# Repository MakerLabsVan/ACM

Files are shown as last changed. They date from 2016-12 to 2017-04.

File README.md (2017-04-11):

# ACM
This system logs and controls access to any machines that are connected to it.
ACM is a central Flask application connected to an Arduino, known as the Front Desk Arduino.
Each machine connected to the system has a module consisting of an Arduino with an RFID chip 
and WiFi capabilities. Every member receives a FOB programmed with their access conditions 
read from a Google Sheet.  
  
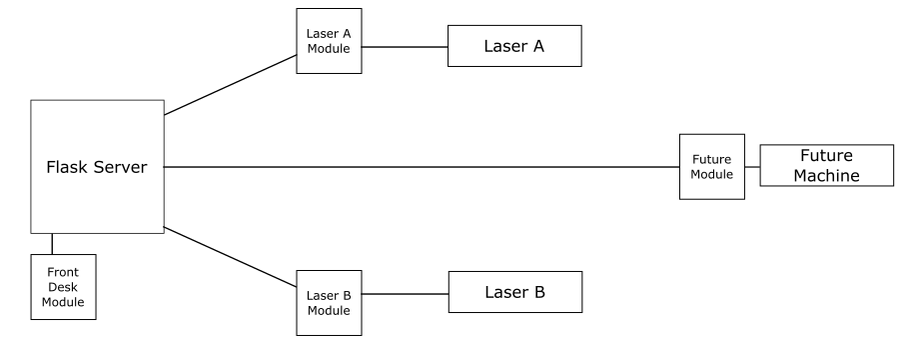
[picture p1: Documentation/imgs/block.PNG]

[block]: https://github.com/MakerLabsVan/ACM/blob/master/Documentation/imgs/block.PNG

# Database
A Google Spreadsheet is used by this app. There is a script (Tools->Script Editor) that runs 
every morning at 1am that goes through each member and determines if his/her membership cycle 
has completed. an email notification is then sent with the member's laser cutter time for that 
cycle. A daily summary is also included in this notification.

# Critical
All WiFi modules are configured to communicate to 192.168.0.200 on MakerLabs-Admin.  
The computer running the ACM app should have a static IP of 192.168.0.200 on MakerLabs-Admin.  
Documentation/wifitest/wifitest.ino should be used to reconfigure the WiFi modules.

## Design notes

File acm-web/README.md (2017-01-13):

# ACM Web Application  
This is a locally run application that serves as a web interface for ACM data and controlling the database. An RFID scanner
is attached through a serial connection to the application. This app can run on Windows, OS X and Linux.

# Requirements  
Flask (http://flask.pocoo.org)  
* SocketIO extension (https://flask-socketio.readthedocs.io/en/latest/)  

AngularJS  
* SocketIO (https://socket.io)  

Python 3 (https://www.python.org/downloads/) 
* PySerial (https://pythonhosted.org/pyserial/)  
* GSpread (https://gspread.readthedocs.io/en/latest/)  

# Installation  
1. Install Python 3 and Flask
2. Install PySerial, GSpread, and Flask-SocketIO modules
3. Follow OAuth2 procedure in GSpread documentation UNLESS still using original spreadsheet.  
   You will still need to install oauth2client `pip install --upgrade oauth2client` and PyOpenSSL `pip install PyOpenSSL`    
   Email Brian for authorization file. See OAuth2 procedure for details on how authorization is obtained.    
   In the database.py file, adjust the relative path to the JSON keyfile if needed.  
   `credentials = ServiceAccountCredentials.from_json_keyfile_name('../../acm-dashboard.json', scope)`
4. App is started by running `python3 server.py`

# Notes
* Photos are uploaded to amazon s3. Photo naming scheme is {id}.jpg

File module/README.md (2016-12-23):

# ACM Modules

This module is designed to authorize access to MakerLabs' laser cutter by an RFID tag. 
The system consists of an Arduino Uno, an RDM880 breakout board, and an ESP8266 breakout 
board. This module actively scans for RFID tags that follow the ISO14443A protocol. Details 
on ISO14443A, specifically MiFare, can be found in ACM/Documentation/ISO14443AB.pdf. This 
module also controls a relay which turns on support systems when a valid tag is detected.  

# Hardware Required
Arduino  
RDM880 (RFID reader)  
ESP8266 (WiFi module)      
LM1117 (3.3V linear regulator)   
IRL530 (n-channel MOSFET)     
LPD8806 LED strip

# Software Required
Arduino IDE  
  * SoftwareSerial library  
  * LPD8806 library
  
# Schematic  
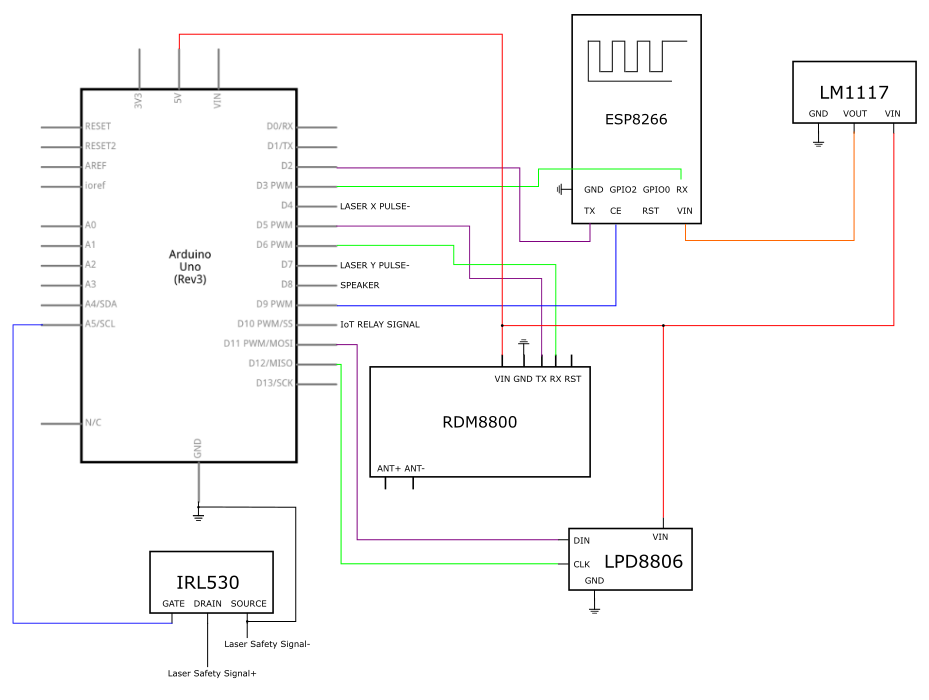
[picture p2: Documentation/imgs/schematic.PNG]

[schematic]: https://github.com/MakerLabsVan/ACM/blob/master/Documentation/imgs/schematic.PNG

# Other Parts and Notes  
__Level Shifter__  
[!alt text][levelshift]
[levelshift]: https://github.com/MakerLabsVan/ACM/blob/master/Documentation/imgs/levelshifter.PNG  
A level shifter is required. Here is an example using a voltage divider. Any value for R can be used as long as
the current going into the RX pin of the WiFi module does not exceed 12 mA.

__WiFi Serial Communication__  
The baud rate of the WiFi module varies with the supplier. Depending on the firmware version, 
the baud rate can be changed through the command set. Otherwise, firmware can be flashed to 
update the command set. The baud rate used here was 9600 for reliable performance with SoftwareSerial. YMMV.    
Tutorial: http://www.instructables.com/id/Intro-Esp-8266-firmware-update/

__Setting up the ESP8266__  
In Documentation/tests/wifi_test, there is a sketch that allows direct access to the ESP8266's serial console.
Upload it to the Arduino, open the serial monitor at 9600 baud and you will be able to use the AT command set as
shown in the command sheet under Documentation/datasheets.

# How It Works
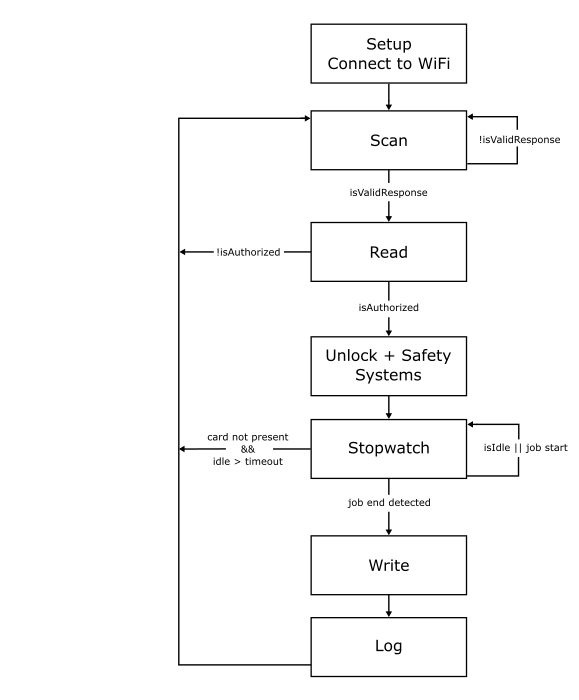
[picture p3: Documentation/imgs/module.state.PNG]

[modulestate]: https://github.com/MakerLabsVan/ACM/blob/master/Documentation/imgs/module.state.PNG  
In the stopwatch state, the module is monitoring the **LASER PLS-** signals of the X and Y motor controllers.
The state of the signals are polled approximately every second (defined as pollInterval) and stored in a circular 
buffer. If 5 (defined as sampleSize) valid signals in a row are detected, the module starts a stopwatch. 
When 5 invalid signals in a row are detected, the module ends the stopwatch and returns back to the main loop, 
where a log is sent to the Flask server.  

Note that there is a period of time where the log is happening between the job end and the start of the next 
loop when the laser cutter is **locked**. This period of time is approximately 3 - 4 seconds depending on 
the network.

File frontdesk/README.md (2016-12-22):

# ACM Front Desk Module

This module is part of the central Flask Server and communicates to it by a serial connection.
See the README in ACM/module for details on the hardware.  

# How It Works
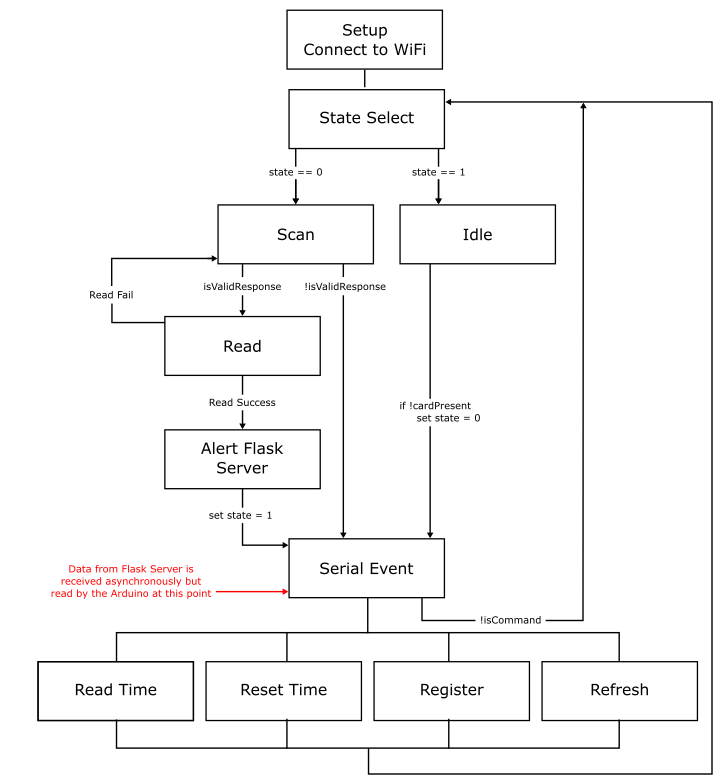
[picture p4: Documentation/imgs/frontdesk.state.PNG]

[frontdeskstate]: https://github.com/MakerLabsVan/ACM/blob/master/Documentation/imgs/frontdesk.state.PNG

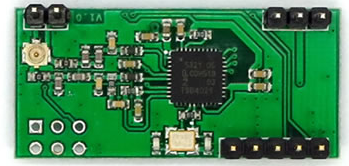
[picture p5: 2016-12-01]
Documentation/imgs/rdm8800.PNG

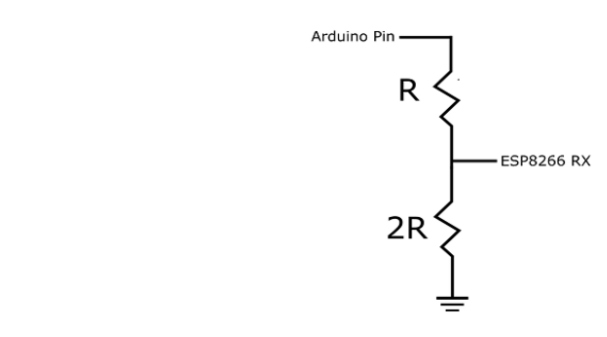
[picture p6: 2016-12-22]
Documentation/imgs/levelshifter.PNG

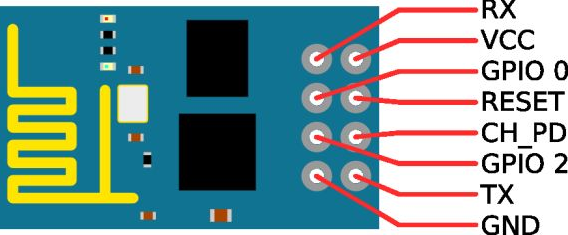
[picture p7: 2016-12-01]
Documentation/imgs/esp8266.PNG

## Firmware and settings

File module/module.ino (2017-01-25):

#include <SoftwareSerial.h>
#include <LPD8806.h>
#include "RFID.h"

#define MODULE

SoftwareSerial WIFI(WIFI_RX, WIFI_TX);
SoftwareSerial RFID(RFID_RX, RFID_TX);
LPD8806 LED = LPD8806(numLEDs, dataPin, clockPin);

int j = 0;

void setup() {
	// Set up pins
	pinMode(ledPin, OUTPUT);
	pinMode(driverX, INPUT);
	pinMode(driverY, INPUT);
	pinMode(speakerPin, OUTPUT);
  	pinMode(interlock, OUTPUT);
	pinMode(supportPin, OUTPUT);
  	pinMode(wifi_rst, OUTPUT);

	// Start with support systems off
	digitalWrite(supportPin, LOW);
	LED.begin();

	// Set up serial communication
	Serial.begin(monitorBaud);
	getStringFromMem(initialize);

	WIFI.begin(moduleBaud);
	connectWIFI();

	// Now listening to RFID serial port
	RFID.begin(moduleBaud);
	getStringFromMem(done);
}

void loop() {
	// some variables
	int8_t isStaff, isAuthorized, isValidResponse = 0;
	int16_t userID = 0;
	unsigned long existingTime, elapsedTime, totalTime = 0;
	unsigned char readData[bufferSize];
	// ----------------------------------------------------------------------
	// Turn LED off, lock laser cutter
	digitalWrite(ledPin, LOW);
	// ----------------------------------------------------------------------
	// Scan for RFID tags and see if support systems need to be off
	getStringFromMem(scan);
	while (!isValidResponse) {
		supportSystem(lastOn);
		sendCommand(CMD_GET_SNR, blockID, machineID, 0);
		delay(waitforSerialResponse);
		isValidResponse = getResponse(readData);
		rainbowCycle();	
	}
	// ----------------------------------------------------------------------
	// RFID tag detected, get user ID and authorization for this machine
	sendCommand(CMD_READ, blockID, userData, 0);
	delay(waitforReadResponse);
	isValidResponse = getResponse(readData);
	userID = (int16_t)getTime(readData, numUserBytes, userOffset);
	isStaff = (int8_t)readData[staffOffset] - ASCII_OFFSET;
	isAuthorized = (int8_t)readData[classOffset] - ASCII_OFFSET;
	// ----------------------------------------------------------------------
	// Read block that contains time data for this machine
	getStringFromMem(detected);
	sendCommand(CMD_READ, blockID, machineID, 0);
	delay(waitforReadResponse);
	isValidResponse = getResponse(readData);
	// -----------------------------------------------------------------------
	// Analyze response packet and data
	if (!isValidResponse) {
		red();		
		playDeath();
		digitalWrite(interlock, LOW);
		getStringFromMem(readUnsuccessful);
	}
	// These statements run if a valid RFID tag is detected
	else {
		// Translate the time data bytes to a value
		existingTime = getTime(readData, numTimeBytes, timeOffset);
		// Check if the user has taken the class and if the card has been initialized
		if ( !userID || !isAuthorized ) {
			red();
			playDeath();
			digitalWrite(interlock, LOW);
			getStringFromMem(notAuthorized);
		}
		// Check if the user has reached the 60 min quota, skip if staff member
		// else if ( (existingTime >= quota) && !isStaff ) {
		// 	red();
		// 	playDeath();
		// 	getStringFromMem(quotaMet);
		// }
		// User passed all checks and is able to use the machine
		// --------------------------------------------------------------------
		else {
			// Sound and text feedback
			green();						
			getStringFromMem(displayUsedTime);
			Serial.println(existingTime);
			getStringFromMem(user);
			Serial.print(userID);
			if (isStaff) {
				getStringFromMem(staff);
			}
			// getStringFromMem(authorized);

			// Ready to accumulate time
			// turn LED and support systems on
			// unlock laser cutter
			digitalWrite(ledPin, HIGH);
			digitalWrite(supportPin, HIGH);
      		digitalWrite(interlock, HIGH);
			elapsedTime = accumulator(readData, elapsedTime);
			totalTime = elapsedTime + existingTime;

			// Job done
			lastOn = millis();
			getStringFromMem(displayNewTime);
			Serial.println(totalTime);
		}
	}
	// -------------------------------------------------------------------------
	// Write time data to card
	if ( isRange(elapsedTime, freeTime, maxTime) ) {
		sendCommand(CMD_WRITE, blockID, machineID, totalTime);
		delay(waitforWriteResponse);
		isValidResponse = getResponse(readData);

		if (!isValidResponse) {
			getStringFromMem(errorRead);
		}
		else {
			getStringFromMem(cardUpdated);
			//delay(timeToRemoveCard);
		}
		// --------------------------------------------------------------------
  		// Push to ACM
		digitalWrite(ledPin, LOW);
		getStringFromMem(sendingLog);
		Serial.println(elapsedTime);
		WIFI.listen();
		updateACM(userID, elapsedTime, existingTime);
		// --------------------------------------------------------------------
		// Finished, prepare for next loop by switching to RFID serial port
		getStringFromMem(done);
		playCoinSound();					
	}
	else {
		Serial.println();
	}

	RFID.listen();
}
/*
	This function monitors the motor driver signals on the laser cutter.
	The signals are PWMs of a specific frequency. This function measures the
	period of any signal detected and accumulates time when valid signals
	are detected. A polling subroutine continuously checks if an RFID tag is 
	still present.
	
	Return: time accumulated
*/
unsigned long accumulator(unsigned char serialNumber[], unsigned long elapsedTime) {
	// some variables used in this scope
	unsigned long startTime, lastPollTime = 0;
	unsigned int periodX, periodY;
	int signals[] = { 0, 0, 0, 0, 0 };
  	int i, numValid, numInvalid, pollCounter = 0;

	if (debug) {
		Serial.print(F(" ")); Serial.print(startTime); Serial.print(F(" ")); Serial.println(elapsedTime);
	}
 
	while (1) {
		// Run approximately every second
		if (timeSince(lastPollTime) > pollInterval) {

			// Polling logic
			sendCommand(CMD_GET_SNR, blockID, machineID, 0);
			// if card is missing, increment a counter
			if (!getResponse(serialNumber)) {
				pollCounter += 1;
				// if the counter reaches a specified timeout, return
				if (pollCounter == pollTimeout) {
					//soundFeedback(isReject);
					getStringFromMem(cancel);
					elapsedTime = calcTime(startTime);

					// Any valid accumulated time will be returned
					if ( (startTime > 0) && isRange(elapsedTime, freeTime, maxTime) ) {
	          			return elapsedTime;
					}
					else {
						return 0;
					}
				}
			}
			else {
				digitalWrite(ledPin, HIGH);
				pollCounter = 0;
			}
			// End Polling Logic

			// Begin signal monitoring logic
			periodX = pulseIn(driverX, HIGH);
			periodY = pulseIn(driverY, HIGH);
	    	signals[i] = isRange(periodX + periodY, 0, maximumValue);

			// Only here temporarily for debugging
			// if (debug) {
			// 	Serial.print(F("PeriodX: ")); Serial.print(periodX); 
			// 	Serial.print(F(" PeriodY: ")); Serial.print(periodY);
			// 	Serial.print(F(" ")); Serial.print(signals[0]); Serial.print(signals[1]); Serial.print(signals[2]); Serial.print(signals[3]); Serial.print(signals[4]);
			// 	Serial.print(F(" ")); Serial.print(numValid); Serial.print(F(" ")); Serial.print(numInvalid);
			// 	Serial.print(F(" Start Time: ")); Serial.print(startTime);
			// 	if (startTime > 0) {
			// 		Serial.print(F(" Elapsed Time: ")); Serial.println(calcTime(startTime));
			// 	}
			// 	else {
			// 		Serial.println(F(" Elapsed Time: 0"));
			// 	}
			// }

			// if periodX and periodY IS a valid pair
			if (signals[i] == 1) {
				numValid += 1;
				numInvalid = 0;

				// a job is detected when we get enough valid signals in a row
				if (numValid == sampleSize) {
					// begin stopwatch
					if (startTime == 0) {
						startTime = millis();
					}
				}
			}

			// if periodX and periodY IS NOT a valid pair
			if (signals[i] == 0) {
				numValid = 0;
				numInvalid += 1;
				
				// check if enough negative signals have been detected
				if (numInvalid == sampleSize) {
					elapsedTime = calcTime(startTime);

					// if a job was detected, return
					if ( (startTime > 0) && isRange(elapsedTime, freeTime, maxTime) ) {
						return elapsedTime;
					}
					else {
						startTime = 0;
						elapsedTime = 0;
						numValid = 0;
						numInvalid = 0;
					}
				}
			}

			i < sampleSize - 1 ? i += 1 : i = 0;
	    	digitalWrite(interlock, HIGH);
			lastPollTime = millis();
		}
	}
}

void red() {
	LED.setPixelColor(0, LED.Color(68, 0, 5));
	LED.setPixelColor(1, LED.Color(127, 16, 25));
	LED.setPixelColor(2, LED.Color(127, 0, 0));
	LED.setPixelColor(3, LED.Color(84, 20, 15));
	LED.show();
}

void rainbowCycle() {
	j == 384 * 5 ? j = 0 : j++;
	for (int i = 0; i < LED.numPixels(); i++) {
		// tricky math! we use each pixel as a fraction of the full 384-color wheel
		// (thats the i / strip.numPixels() part)
		// Then add in j which makes the colors go around per pixel
		// the % 384 is to make the wheel cycle around
		LED.setPixelColor(i, Wheel( ((i * 384 / LED.numPixels()) + j) % 384) );
	}  
	LED.show();   // write all the pixels out
}

void green() {
	LED.setPixelColor(0, LED.Color(5, 0, 68));
	LED.setPixelColor(1, LED.Color(25, 16, 127));
	LED.setPixelColor(2, LED.Color(10, 0, 127));
	LED.setPixelColor(3, LED.Color(20, 14, 84));
	LED.show();
}

uint32_t Wheel(uint16_t WheelPos)
{
  byte r, g, b;
  switch(WheelPos / 128)
  {
    case 0:
      r = 127 - WheelPos % 128;   //Red down
      g = WheelPos % 128;      // Green up
      b = 0;                  //blue off
      break; 
    case 1:
      g = 127 - WheelPos % 128;  //green down
      b = WheelPos % 128;      //blue up
      r = 0;                  //red off
      break; 
    case 2:
      b = 127 - WheelPos % 128;  //blue down 
      r = WheelPos % 128;      //red up
      g = 0;                  //green off
      break; 
  }
  return(LED.Color(r,g,b));
}

void playCoinSound() {
	int coinNotes[] = { 988, 1319 };
	int coinNoteDurations[] = { 125, 400 };
	int numCoinNotes = numElements(coinNotes);

	for (int i = 0; i < numCoinNotes; i++) {
        tone(speakerPin, coinNotes[i]);
        delay(coinNoteDurations[i]);
        noTone(speakerPin);
    }
}

void playDeath() {
	int notes[] = { 247, 247, 247 };
	int numNotes = numElements(notes);

	for (int i = 0; i < numNotes; i++) {
		tone(speakerPin, notes[i]);
		delay(150);
		noTone(speakerPin);
		delay(150);
	}
}

void getStringFromMem(int index) {
	char stringBuffer[stringSize];
	strcpy_P(stringBuffer, (char*)pgm_read_word( &(message[index])) );
	Serial.print(stringBuffer);
}

void supportSystem(unsigned long lastOn) {
	// check if the support systems are on
	if (digitalRead(supportPin) == HIGH) {
		// check if it's been more than 5 mins
		// since the last card was scanned
		if (timeSince(lastOn) > supportTimeout) {
			digitalWrite(supportPin, LOW);
		}
		if (timeSince(lastOn) > interlockTimeout) {
			digitalWrite(interlock, LOW);
		}
	}
}

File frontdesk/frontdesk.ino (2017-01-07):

#include <SoftwareSerial.h>
#include <LPD8806.h>
#include "RFID.h"

#define FRONTDESK

SoftwareSerial RFID(RFID_RX, RFID_TX);
SoftwareSerial WIFI(WIFI_RX, WIFI_TX);

int j = 0;
LPD8806 LED = LPD8806(numLEDs, dataPin, clockPin);

int pollCounter, scannedID = 0;
unsigned char readData[bufferSize];

volatile bool isValidResponse = false;
volatile char characterRead[bufferSize];
volatile int state, id = 0;

void setup() {
	Serial.begin(moduleBaud);
	WIFI.begin(moduleBaud);
  	LED.begin();

	pinMode(ledPin, OUTPUT);
	pinMode(wifi_rst, OUTPUT);
	pinMode(speakerPin, OUTPUT);

	connectWIFI();
  	LED.show();
	RFID.begin(moduleBaud);
}

void loop() {
	// Scan
	if (state == 0) {
		sendCommand(CMD_GET_SNR, blockID, machineID);
		delay(waitforSerialResponse);
		isValidResponse = getResponse(readData);

		digitalWrite(ledPin, LOW);
		rainbowCycle();

		// If a tag is detected, read data and alert web app
		if (isValidResponse) {
			sendCommand(CMD_READ, blockID, userData);
			delay(waitforReadResponse);
			isValidResponse = getResponse(readData);

			// If data is successfully read, alert web app
			if (isValidResponse) {
				scannedID = (int)getTime(readData, numUserBytes, userOffset);

				// LEDs on
				green();
				digitalWrite(ledPin, HIGH);
				playCoinSound();
				WIFI.listen();
				
				// Constrain ID range for now... need to figure out why
				// large IDs are being sent randomly
				if ( isRange(scannedID, 0, 500) ) {
					scanTest(scannedID);
				}

				RFID.listen();
				state = 1;
			}
			else {
      			red();
				playDeath();
				state = 0;
			}
		}
	}
	// Other tag operations
	else if (state == 1) {
		sendCommand(CMD_GET_SNR, blockID, machineID);
		delay(waitforSerialResponse);
		isValidResponse = getResponse(readData);

		// If tag is removed, go back to scan state
		if (!isValidResponse) {
      		pollCounter++;
      		if (pollCounter == scan) {
        		state = 0;
        		pollCounter = 0;  
      		}
		}
	}
	// Go back to scan state otherwise
	else {
		state = 0;
	}
}

/* This functions runs after every time loop runs */
void serialEvent() {
	int i = 0;
	unsigned long existingTime = 0;

	while (Serial.available()) {
		// if no tag present, consume all data and send error
		if (state == 0) {
			while (Serial.available()) {
				Serial.read();
			}
			Serial.write(ERROR_CHAR);
			Serial.write(END_CHAR);
		}
		// otherwise, receive data and process
		else {
			characterRead[i] = Serial.read();
			i++;
		}
	}

	if (characterRead[0]) {
		// Read the time on card
		if (characterRead[0] == COMMAND_GET_TIME) {
			characterRead[0] = 0;

			sendCommand(CMD_READ, blockID, machineID);
			delay(waitforReadResponse);
			isValidResponse = getResponse(readData);
			existingTime = getTime(readData, numTimeBytes, timeOffset);

			// Send it to ACM
			while (existingTime) {
				Serial.write(existingTime);
				existingTime >>= eightBits;
			}
			
			Serial.write(END_CHAR);
		}

		// Reset the time on card
		else if (characterRead[0] == COMMAND_RESET_TIME) {
			characterRead[0] = 0;

			preparePayload(COMMAND_RESET_TIME, 0, 0, 0);
			sendCommand(CMD_WRITE, blockID, machineID);
			delay(waitforWriteResponse);

			Serial.write(done);
			Serial.write(END_CHAR);
		}

		else if (characterRead[0] == COMMAND_REGISTER) {
			characterRead[0] = 0;

			int numDigits = (int)(characterRead[1] - ASCII_OFFSET);		
			convertASCII(numDigits);

			preparePayload(COMMAND_REGISTER, id, numDigits, 0);
			sendCommand(CMD_WRITE, blockID, userData);
			delay(waitforWriteResponse);

			// Make sure time on card is zero when registered
			if (id) {
				preparePayload(COMMAND_RESET_TIME, 0, 0, 0);
				sendCommand(CMD_WRITE, blockID, machineID);
				while (id) {
					Serial.write(id);
					id >>= eightBits;
				}
			}

			Serial.write(END_CHAR);
			playUnderground();
		}

		// Update card permissions
		else if (characterRead[0] == COMMAND_REFRESH) {
			characterRead[0] = 0;
			
			int numDigits = (int)(characterRead[1] - ASCII_OFFSET);				
			convertASCII(numDigits);

			preparePayload(COMMAND_REGISTER, id, numDigits, 0);
			sendCommand(CMD_WRITE, blockID, userData);
			delay(waitforWriteResponse);

			while (id) {
				Serial.write(id);
				id >>= eightBits;
			}

			Serial.write(END_CHAR);
			playUnderground();
		}
	}
}

void convertASCII(int numDigits) {
	for (int i = 0; i < numDigits; i++) {
		id *= 10;
		id += (int)(characterRead[i+2] - ASCII_OFFSET);
	}
}

void getStringFromMem(int index) {
	char stringBuffer[stringSize];
	strcpy_P(stringBuffer, (char*)pgm_read_word( &(message[index]) ));
	Serial.print(stringBuffer);
}

void playCoinSound() {
	int coinNotes[] = { 988, 1319 };
	int coinNoteDurations[] = { 125, 400 };
	int numCoinNotes = numElements(coinNotes);

	for (int i = 0; i < numCoinNotes; i++) {
        tone(speakerPin, coinNotes[i]);
        delay(coinNoteDurations[i]);
        noTone(speakerPin);
    }
}

void playUnderground() {
	int notes[] = { 131, 262 };
	int numNotes = numElements(notes);

	for (int i = 0; i < numNotes; i++) {
		tone(speakerPin, notes[i]);
		delay(200);
		noTone(speakerPin);
	}
}

void playDeath() {
	int notes[] = { 247, 247, 247 };
	int numNotes = numElements(notes);

	for (int i = 0; i < numNotes; i++) {
		tone(speakerPin, notes[i]);
		delay(150);
		noTone(speakerPin);
		delay(150);
	}
}

void green() {
	LED.setPixelColor(0, LED.Color(5, 0, 68));
	LED.setPixelColor(1, LED.Color(25, 16, 127));
	LED.setPixelColor(2, LED.Color(10, 0, 127));
	LED.setPixelColor(3, LED.Color(20, 14, 84));
	LED.show();
}

void red() {
	LED.setPixelColor(0, LED.Color(68, 0, 5));
	LED.setPixelColor(1, LED.Color(127, 16, 25));
	LED.setPixelColor(2, LED.Color(127, 0, 0));
	LED.setPixelColor(3, LED.Color(84, 20, 15));
	LED.show();
}

void colorWipe(uint32_t c) {
	for (int i = 0; i < LED.numPixels(); i++) {
		LED.setPixelColor(i, c);
		LED.show();
	}
}

void rainbow() {
	j == 384 ? j = 0 : j++;

	for (int i = 0; i < LED.numPixels(); i++) {
		LED.setPixelColor(i, Wheel( (i + j) % 384));
	}
	LED.show();   // write all the pixels out
}

void rainbowCycle() {
	j >= 384 ? j = 0 : j += 7;

    for (int i = 0; i < LED.numPixels(); i++) {
		// tricky math! we use each pixel as a fraction of the full 384-color wheel
		// (thats the i / strip.numPixels() part)
		// Then add in j which makes the colors go around per pixel
		// the % 384 is to make the wheel cycle around
		LED.setPixelColor(i, Wheel( ((i * 384 / LED.numPixels()) + j) % 384) );
    }  

    LED.show();
}
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

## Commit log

2016-05-30 Added comments about circuit
2016-05-31 Added documentation and LED functionality
2016-06-02 Calibrated debounce delay
2016-06-06 fixed some errors, ready for testing
    [reader_test.ino]
2016-06-07 read/write combination does not work
    [writer_test.ino]
2016-06-07 testing, problem with serial timing
    [module.ino]
2016-06-14 Modified poll to not interfere with the return part of the accumulator function
    [module.ino]
2016-06-15 Communication between Arduino and Wi-Fi modulesuccessfully established
2016-06-16 400 Bad Request issue persists
    [wifi_test.ino]
2016-06-17 Version 2.05. Fixed time writing error.
    [module.ino]
2016-06-21 GET request successful. Need to find way to switch back to RFID functionality.
2016-06-21 successfully switched to RFID functionality by button press
2016-06-22 Added memory breakdown of card
    [CardProtocol.xlsx]
2016-06-22 Motor driver datasheet
2016-06-22 memory structure complete
    [CardProtocol.xlsx]
2016-06-22 Testing a PWM detector ISR
2016-06-24 enclosure design file
2016-06-24 tested on laser cutter
2016-06-24 created basic schematic of project
    [module.schematic.fzz]
2016-06-28 Test works without noise
    [pwm_detector_test.ino]
2016-06-30 filtering some data
2016-06-30 fixed bug in timestamping
    [pwm_detector_test.ino]
2016-07-04 Fixed bug in hardware serial declaration
    [pwm_detector_test.ino]
2016-07-04 Found that when cutter is off, noise can trigger a log to send
    [pwm_detector_test.ino]
2016-07-04 Adding pwm logs for debugging
2016-07-04 Added PWM data
2016-07-04 Added delay before time log to send at correct intervals
    [pwm_detector_test.ino]
2016-07-04 integrated new pwm signal detector
2016-07-04 RFID tag stuck on reader to continue logging
    [module.ino]
2016-07-04 Fixed typo in polling logic
    [module.ino]
2016-07-05 Fixed bug in ThingSpeak log
    [RFID.h, module.ino]
2016-07-05 Added one more valid pair for drivers
2016-07-05 Fixed bug in valid pair detection
    [module.ino]
2016-07-05 fixing bug in writing new time
    [module.ino]
2016-07-05 Found that module.ino does not process Arduino String data type correctly.
    [module.ino]
2016-07-05 Fixing String datatype error
    [RFID.h, module.ino]
2016-07-05 String concatenation not working in 2nd function call
    [RFID.h, module.ino]
2016-07-07 Fixed flaw where removing card would not update ThingSpeak
    [module.ino]
2016-07-07 Fixed bug where module would not activate WiFi serial port
    [module.ino]
2016-07-13 Reverted back to rising edge logic
    [module.ino]
2016-07-14 Design file for enclosure
2016-07-18 Clean up. Fixed overflow issue
    [module.ino]
2016-07-18 This version is for the Arduino with integrated WiFi
2016-07-19 Adding serial debugging for small laser
2016-07-19 Code was in wrong branch of repo
    [RFID.h]
2016-07-20 Monitoring small laser cutter
2016-07-21 Modified to monitor small laser
2016-07-23 new enclosure
2016-07-24 small laser enclosure
2016-07-25 Fixing bug related to RFID not initializing if on Uno WiFi
    [module.ino]
2016-07-25 Testing blinking LED at polling
2016-07-25 Fixed bug in function declaration
    [module.ino]
2016-07-26 Signal detection is not working
    [RFID.h, module.ino]
2016-07-26 Testing on small laser
2016-07-26 Fixed bug in string retrieving
    [RFID.h, module.ino]
2016-08-03 Added error check for time data
    [frontdesk.ino]
2016-08-04 Fixed bug in serial printing
    [module.ino]
2016-08-04 Fixed bug in front desk minutes calculation
    [frontdesk.ino, module.ino]
2016-08-08 Fixed bug in signal validation
    [RFID.h]
2016-08-08 Switching to timed polling instead of delaying
2016-08-08 Testing LED blink when card not detected during job
2016-08-08 Testing LED blink when card not detected during job 2
2016-08-08 Testing LED blink when card not detected during job 3
2016-08-15 Testing LED blink on poll
2016-08-15 LED blink causing issues with serial monitor
    [module.ino]
2016-08-15 Removed LED logic
2016-08-18 Fixed bug in staff member detection. Need to update all staff cards
    [RFID.h, module.ino]
2016-08-18 Fixed small laser wifi module
    [wifi_test.ino]
2016-08-22 Fixed bugs in front desk
    [frontdesk.ino, module.ino]
2016-08-23 Started on mini web app to control arduino through serial port
2016-08-24 One way communication with Arduino established
2016-08-24 Able to send command to turn on and off LED
2016-08-24 Successfully tested two way communication between PC and Arduino
2016-08-24 Testing get time and reset functions from web interface
    [frontdesk.ino]
2016-08-24 Created class that interfaces with arduino
2016-08-25 debugging issue with port synchronization
    [arduino.py]
2016-08-25 Determined cause of serial comm failure
    [arduino.py, constant.py, frontdesk.ino]
2016-08-25 Successfully controlled front desk acm through serial port. Returns correct time as well
    [arduino.py, constant.py, frontdesk.ino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]
2016-08-26 Modified all function names and replaced all references
    [arduino.py, constant.py, serialcommtest.ino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]
2016-08-30 Added error checking for cards that aren't scanned
    [arduino.py, constant.py, server.py]
2016-08-30 Removed error check and now adding wait
    [arduino.py, constant.py]
2016-08-30 testing an error check
    [arduino.py]
2016-09-03 Successfully send data from web app form to arduino and parsed correctly
    [frontdesk.ino]
2016-09-06 Fixing bug where only 1 card can be registered in one session
    [frontdesk.ino]
2016-09-06 Added auto reset to card after registration
    [frontdesk.ino]
2016-09-06 Changed name of button
2016-09-07 Testing automatic calculation of laser time cost
2016-09-07 Added auto calculation of drop in laser rate
2016-09-08 Fixed bug in choosing host
    [arduino.py]
2016-09-08 Added hole for keychain
2016-09-23 Fixed bug in time not writing to card. Modified delay
    [RFID.h]
2016-09-23 Fixing bug in writing to card
    [RFID.h, module.ino]
2016-09-23 Fixed data type of authorization
    [module.ino]
2016-09-26 Successfully tested insert of user
2016-09-27 Fixed and synced up user model
    [constant.py, database.py]
2016-09-27 Reverting to previous version due to bugs in writing
    [RFID.h, module.ino, module_rfid.ino]
2016-09-27 Reverting to previous version due to bug in writing
    [module.rfid.ino, module.wifi.ino]
2016-09-27 RFID was not finished sending data before Arduino stopped listening. Modified listen function. Fixed writing bug
    [RFID.h, module.rfid.ino]
2016-09-27 Fixed redeclaration of variables
    [frontdesk.ino]
2016-09-29 Fixing conflicts from merge
    [RFID.h, frontdesk.ino, module.rfid.ino]
2016-09-30 Testing Arduino WiFi with web app
2016-09-30 Accidentally pulled wrong branch. Reverting changes
    [server.py]
2016-09-30 Testing api call from arduino uno
2016-09-30 Arduino Uno Wifi only works with thingspeak... testing
2016-10-01 Changing main loop to only scan for cards. Serial interrupt will handle commands
2016-10-01 Fixed bug in one time scanning
    [frontdesk.ino]
2016-10-01 Added error check for id being zero
    [frontdesk.ino]
2016-10-01 Beginning laser cutter log api
2016-10-01 Successfully tested laser log api
2016-10-01 Successfully posted to laser log sheet. Need to integrate with modules
2016-10-03 Successfully tested laser cutter log api call
2016-10-04 done logging for laser cutter
2016-10-04 Fixed bug in datetime implementation
    [database.py, server.py]
2016-10-04 Modifying print formatting
2016-10-04 fixed a comment about converting byte stream to number
    [arduino.py]
2016-10-04 Added lifetime laser cutter time
2016-10-04 Reactivated arduino
2016-10-04 Fixed bug in logging time
    [database.py]
2016-10-04 Removed laser access option
2016-10-05 Removing lifetime log. Causing bugs
    [database.py]
2016-10-05 Fixed bug where arduino received ascii
    [RFID.h, module.ino]
2016-10-06 Reverting front-desk to prev version
    [frontdesk.ino]
2016-10-06 successfully tested socket, integrating into app
2016-10-07 Currently working, but need to integrate with angular
2016-10-07 implemented on arduino
2016-10-07 removing arduino section for testing
2016-10-12 Logging lifetime laser time and month's laser time
2016-10-12 Removed socket until needed
2016-10-12 Fixed bug with return values
    [database.py]
2016-10-13 Cut down on extra api calls
2016-10-14 Printing authorization time
2016-10-14 Fixed bug with timedelta function. Added total_seconds
    [database.py]
2016-10-18 Added missing time variable
    [module.ino]
2016-10-18 Fixed bug with header file
    [RFID.h]
2016-10-18 Changing support pin to an available digital pin
2016-10-19 Removed unnecessary row check code. Found bug was due to token refresh. Got rid of microseconds in time data as well.
    [database.py, server.py]
2016-10-19 Forgot to uncomment arduino code
2016-10-20 Added wifi module to frontdesk arduino. Successfully communicated with server
2016-10-20 Added scan log and testing new laser log
2016-10-20 Fixed logging of guest cards
    [database.py, server.py]
2016-10-20 only adding to db if arduino successfully registers
2016-10-20 Fixed return value bug
    [database.py]
2016-10-20 Fixed tab and spacing error
    [database.py]
2016-10-20 data now refers to correct element
    [database.py]
2016-10-21 Adding socket
2016-10-21 Socket tested and working
2016-10-21 Fixed reference to data
    [server.py]
2016-10-21 Fixed off by one error when logging
    [database.py]
2016-10-21 Added constant for laser times
2016-10-24 Adding quick fix for scan errors
    [frontdesk.ino]
2016-10-25 trying to do tab pane switch in angular
2016-10-26 Switched all ACM related modules to Admin network
2016-10-26 Tab pane switching logic is done through angular now
2016-10-27 adding quick fix for scan log
    [server.py]
2016-10-27 Centered registration button. Added more user info
2016-10-27 Fixed non display of laser time
2016-10-28 Button highlights
2016-10-28 Added button disable until a response is received. Prevents button spamming
    [server.py]
2016-10-28 testing auto switch to main tab on scan
2016-10-31 Reactivated arduino code
2016-11-03 Added led strip logic
2016-11-03 testing led strip
2016-11-03 Fixed drop in charge display
2016-11-03 Testing other LED functions
2016-11-03 Testing LED changes
2016-11-03 Added bad read sound
    [module.schematic.fzz]
2016-11-03 case plans
2016-11-04 Added hole for barrel jack
2016-11-04 Added hole for usb
2016-11-04 Fixed bug in call to web app
    [frontdesk.ino]
2016-11-05 Ready to cut
2016-11-06 Fixed styling of submit buttons
2016-11-06 Added error msg when command is sent with no card present
    [frontdesk.ino]
2016-11-06 raspi enclosure
2016-11-09 Cut down on sound effects
2016-11-09 Fixed app freeze when sending command without card present
    [frontdesk.ino]
2016-11-09 Fixing bug with staff offset
    [server.py]
2016-11-09 LED strip added
2016-11-09 Testing auto reset time every month
    [server.py]
2016-11-10 Shorten registration/refresh sound lenght
    [frontdesk.ino]
2016-11-16 Updated drop in charge on scan
2016-11-16 fixing drop in charge
2016-11-20 Added another socket event for refresh status
2016-11-23 Testing method that replaces an existing users id with a new one
    [database.py, server.py]
2016-11-24 Testing user id replacement
    [server.py]
2016-11-30 Checking laser log
2016-12-01 pin details
2016-12-02 Hiding laserB
2016-12-06 Added schematic, cleaned up files
2016-12-06 added colour to schematic
2016-12-06 Fixed pin assignment. Added LED strip.
2016-12-06 Added speaker pin
2016-12-08 Arduino does not support C++ optional param feature. It supports overloading.
2016-12-08 Fixed reset time return value
    [frontdesk.ino]
2016-12-15 Clean up and reactivated arduino
2016-12-15 added new tab for laser data display
2016-12-15 Fixed bug with serial commands
    [frontdesk.ino]
2016-12-16 fixed serial command error
    [frontdesk.ino]
2016-12-17 Got laser data onto acm in tables
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2016-12-20 Changing laser logs to append
2016-12-21 Removed vestigial files
    [CardProtocol.xlsx]
2016-12-21 fixed issue of missing return value in registration
    [server.py]
2016-12-23 Making interlock less strict to prevent rare case where it interferes with a job
    [RFID.h, module.ino]
2017-01-07 bug fixes. changed user image databse to aws s3.
    [RFID.h, arduino.py, frontdesk.ino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]
